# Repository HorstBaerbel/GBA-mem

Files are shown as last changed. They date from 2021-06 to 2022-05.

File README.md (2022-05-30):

<p align="center">
    <span>
        <font size="12">Here be dragons🐉!</font></br>
        <font size="4">This killed my GBA. I probably fried the power supply IC. I'm leaving this here for academic purposes...</font>
    </span>
</p>

# Game Boy Advance faster EWRAM hack

The GBA has 256kB of external work RAM in the form of an 128kx16 SRAM chip with 70ns (M68AS128DL70N6), 85ns ([μPD442012AGY-BB85X-MJH](http://www.dexsilicium.com/Nec_D442012AGY.pdf)), or even 120ns ([HY62LF16206A-LT12C](https://www.alldatasheet.com/datasheet-pdf/pdf/96180/HYNIX/HY62LF16206A.html)) access time, depending on the chip (good hardware database [here](https://gbhwdb.gekkio.fi/consoles/agb/)). The regular EWRAM access speed is 2 wait states (3/3/6 clock cycles) for 1/2/4 bytes of data. Setting the [undocumented EWRAM wait states flags](http://problemkaputt.de/gbatek.htm#gbasystemcontrol) to 0Eh allows you to speed up EWRAM access to 1 wait state (2/2/4 clock cycles). Setting it to 0Fh will crash / lock up the GBA though, because 0 wait states are out of the specs of all SRAM chips ever used in the GBA / GBA SP and GBA Micro (access times must be < 62ns) and EWRAM gets corrupted (see [testing memory](#testing-memory)). The choice of those SRAM chips back in 2000 was probably due availability and keeping the system costs down, but 20 years later there are cheap SRAM chips available with as low as 10ns access time, so...

## The hardware

This aims to replace the GBAs SRAM chip with a faster chip on a carrier board, because there seem to be no pin-compatible models anymore. The old models used a TSOP-I-48 footprint, newer models use a TSOP-II-44 footprint and all have a very different pinout.

<p align="center">
    <span>
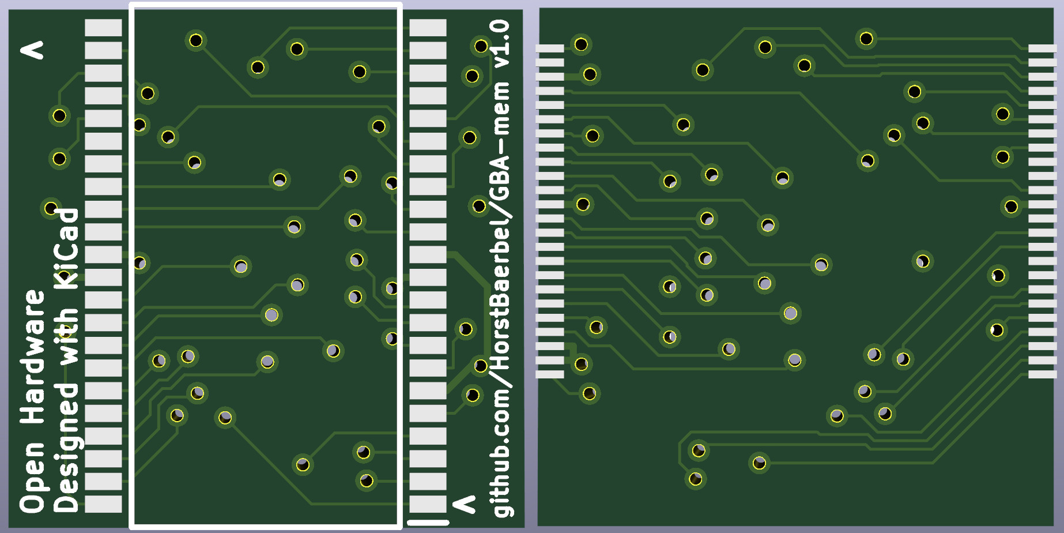
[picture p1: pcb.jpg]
schematics
        
    </span>
</p>

Supposedly compatible SRAM chips for the board:

| Model | min. access time | max. power draw | working |
| --- | --- | --- | --- |
| [IS62WV12816BLL-55TLI / -55BLI](http://www.issi.com/WW/pdf/62WV12816ALL.pdf) | 55ns | ~25mA | NO (tested) |
| [IS62WV12816EBLL-45TLI](http://www.issi.com/WW/pdf/62-65WV12816EALL-BLL.pdf) | 45ns | ~15mA | ? |
| [CY62136FV30LL-45ZSXIT / -45ZSXI / -45ZSXA](https://www.cypress.com/file/43866/download) | 45ns | ~18mA | ? |
| [CY62136ESL-45ZSXI](https://www.mouser.de/datasheet/2/100/001-48147_CY62136ESL_MoBL_R_2-Mbit_128_K_X_16_Stat-319203.pdf) | 45ns | ~20mA | ? |

The power draw of the replacement chips seems to be comparable to that of the originals. I'd go with the IS62WV12816EBLL-45TLI if you can find it, because of the lowest power draw.

## Making your own boards

The [KiCad](KiCad) directory contains the schematics and PCB layout and also gerber files (exported for JLPCB). I chose [JLPCB](https://jlcpcb.com) as a manufacturer in this case and a board thickness of 0.8mm. Remember to get a stencil made for both sides.

### Soldering

I opted for [ChipQuik Sn42/Bi58 TS391LT](https://www.amazon.de/gp/product/B0195V1QEI) solder paste because of its low melting point of 138°C. This makes it easier to solder and you need to heat up the GBA mainboard less. You can 3D-print a [PCB holder](STL/PCB_holder.stl) for the PCB to apply solder paste with the stencil:

<p align="center">
    <span>
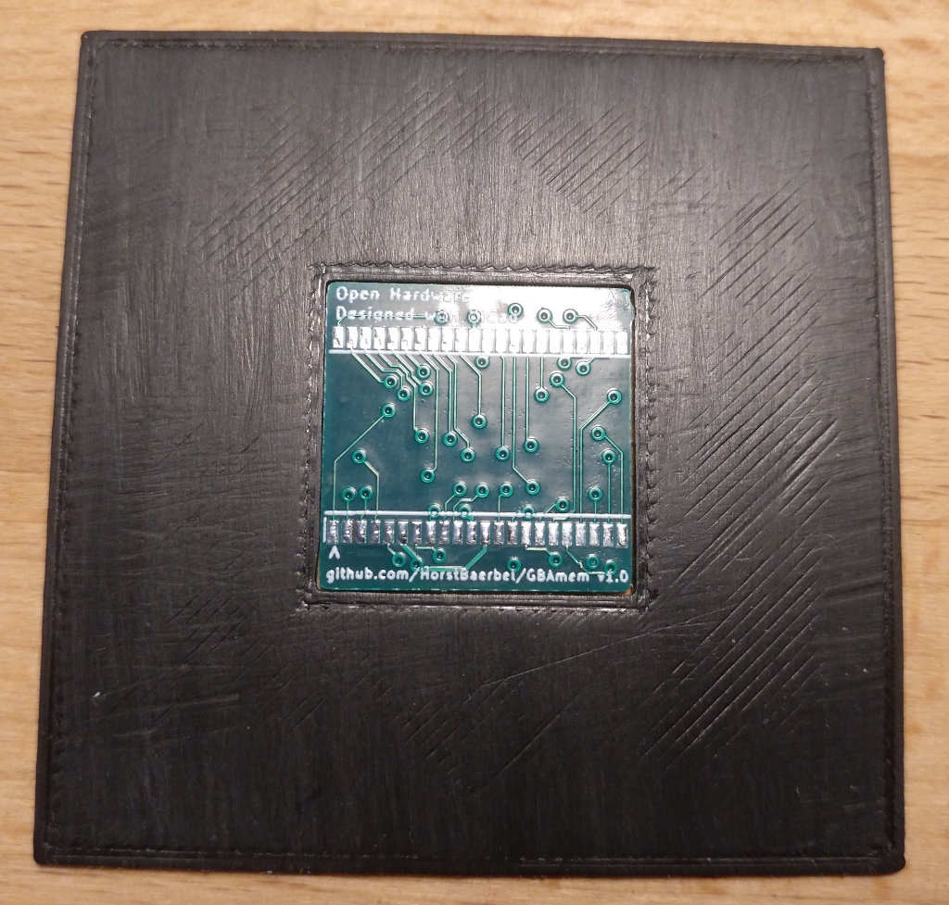
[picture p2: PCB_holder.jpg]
PCB holder
        
    </span>
</p>

It will test the ROM read, EWRAM read / write and IWRAM ⟷ EWRAM copy speed (startup default, Button **A**). Memory is copied in 24kB blocks, so this is not the max. speed possible, but gives a ballpark number. You can also test the memory for errors ([Memtest86+](http://www.memtest.org/)-like, Button **B**). Buttons **L** and **R** let you increase or decrease the EWRAM timings, **⟵** and **⟶** let you increase or decrease the ROM wait states and **START** reboots the GBA. The source code can be found in the [src](src) directory.  
**Theoretical** EWRAM SRAM chip transfer speeds should be: Clock speed * 2 (16 bit SRAM width) / (1 + wait states) ⟷ 16 * 1024 * 1024 * 2 / (1 + w) = 10.6 MB/s (default 2 wait states) and 32 MB/s (0 wait states).

## How to build the test binary?

### From the command line

* You **must** have [CMake](https://cmake.org/) 3.1.0 or higher, [devkitPro / devKitARM](https://devkitpro.org) r58 or higher [installed](https://devkitpro.org/wiki/Getting_Started).
* Navigate to the [src](src) folder, then:

```sh
mkdir build && cd build
cmake -DCMAKE_BUILD_TYPE=Release ..
make -j $(grep -c '^processor' /proc/cpuinfo 2>/dev/null)
```

### From Visual Studio Code

* You **must** have [CMake](https://cmake.org/), [devkitPro / devKitARM](https://devkitpro.org) r54 or higher [installed](https://devkitpro.org/wiki/Getting_Started).
* **Must**: Install the "C/C++ extension" by Microsoft.
* **Recommended**: If you want intellisense functionality install the "C++ intellisense" extension by austin.
* **Must**: Install the "CMake Tools" extension by Microsoft.
* Restart / Reload Visual Studio Code if you have installed extensions.
* Open the GBAmem folder using "Open folder...".
* Choose "Unspecified" as your active CMake kit if asked. It then should be autodetected correctly.
* You should be able to build now using F7 and build + run using F5.

## License

If you want to build your own soft- or hardware based on this, you can. See the [MIT LICENSE](LICENSE).  
The "Modern DOS" 8x8 font is from [Jayvee Enaguas](https://notabug.org/HarvettFox96/ttf-moderndos) and used by [CC0](https://notabug.org/HarvettFox96/ttf-moderndos/src/master/LICENSE).  
The CMake build scripts / toolchain is from [Thomas Farr](https://github.com/Xtansia/3ds-cmake) and uses the [MIT LICENSE](3ds-cmake/LICENSE).

## Todo

* Move all of the code to IWRAM
* Use framework
* Test IS62WV12816EBLL-45TLI
* Try out [AGZ PCB](https://github.com/Zekfoo/AGZ)

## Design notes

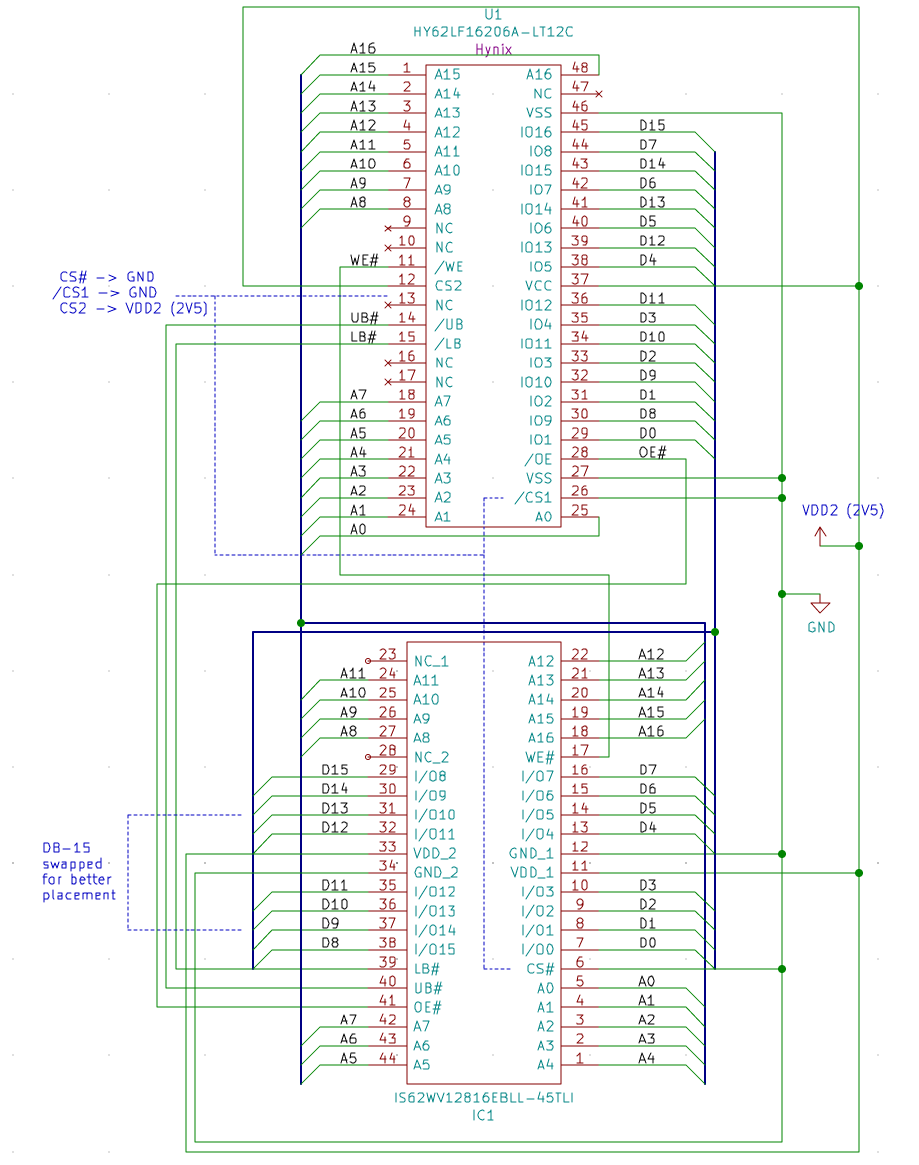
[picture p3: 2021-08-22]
schematics.png

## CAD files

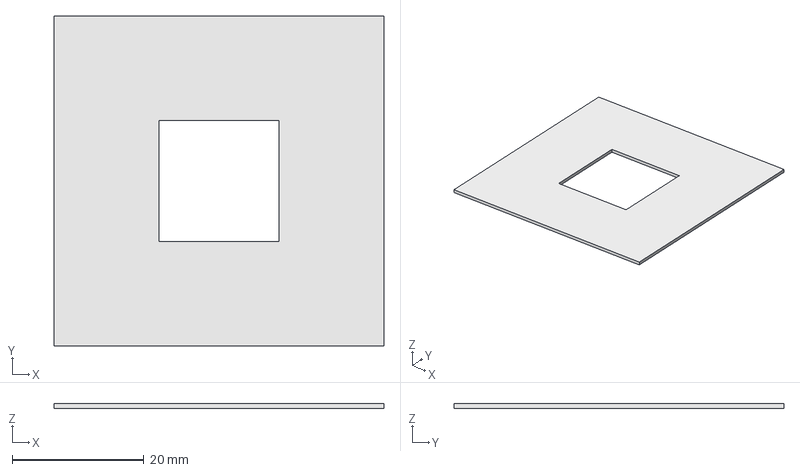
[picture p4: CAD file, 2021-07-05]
STL/PCB_holder.FCStd
50.0 x 50.0 x 0.7 mm

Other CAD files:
STL/PCB_holder.stl

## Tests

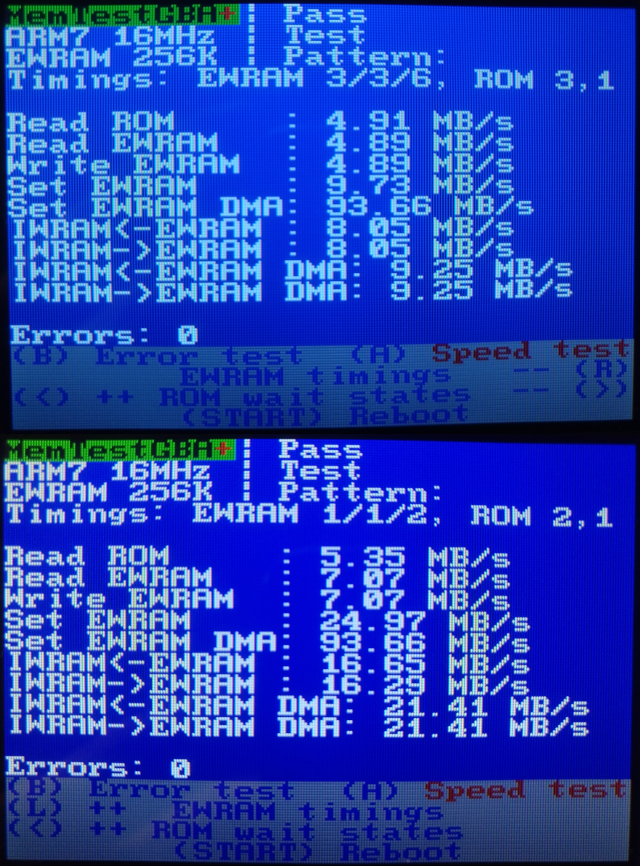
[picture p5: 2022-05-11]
MemTestGBA.png

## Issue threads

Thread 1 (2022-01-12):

About this project

StephS, 2022-01-12:
Hey, I found this thinking the same thing, and it looks like you're the only one who has tried this.
But I see your warning, and the short table that seems to state that none of the memory worked.
Any idea what went wrong?

HorstBaerbel, 2022-01-12:
The GBA started the test ROM for a couple of seconds, but then died. I think the power supply was not sufficient for the chip I used (IS62WV12816BLL). I unsoldered the chip and the GBA starts and boots due to IWRAM being available, but when loading ROMs it crashes obviously. I haven't found the time to try soldering the old RAM chip again or trying out the IS62WV12816EBLLs I have lying around here.
There's a [GBA PCB / circuit redesign](https://github.com/Zekfoo/AGZ) that would be perfect for trying this out.

HorstBaerbel, 2022-01-12:
You can also find me on [discord/gbadev](https://discord.io/gbadev) if you want.

Closed 2022-01-12.

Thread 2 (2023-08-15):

Exploring the Feasibility of Expanding GBA Memory

panzoe, 2023-08-15:
Hello,

I came across this project and I'm genuinely impressed by its capabilities. However, it seems the project primarily focuses on achieving higher memory frequencies. I'd like to inquire whether it's possible to expand the memory capacity of the GBA. The current memory size is quite restrictive, especially when it comes to creating custom programs for the GBA.

Is it feasible to consider replacing the existing eWRAM chip or even introducing an additional eWRAM-like chip into the circuit to provide more memory for program utilization? For instance, is there a way to increase the memory to 64/128/256/512MB?

HorstBaerbel, 2023-08-15:
Hi panzoe.
The GBA CPU only has enough address lines for addressing 256kB of external memory / EWRAM. Switching memory chips / address lanes is not a good idea due random memory accesses being impossible and afaik the stack being in EWRAM too. So, no I guess.
That said 256kB EWRAM + 32kB IWRAM + 96kB VRAM is a good amount of memory for such a system. If that's not enough for you, you're probably "doing it wrong". On limited systems you have to get creative, cut corners, pre-process as much as you can.

Closed 2023-08-15.

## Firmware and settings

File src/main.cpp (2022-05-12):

#include <gba_base.h>
#include <gba_input.h>
#include <gba_interrupt.h>
#include <gba_systemcalls.h>
#include <gba_timers.h>
#include <gba_video.h>

#include "data/romdata.h"
#include "dma.h"
#include "itoa.h"
#include "memory.h"
#include "tui.h"

struct alignas(4) TestConfig
{
	uint8_t *dest = nullptr;
	uint32_t destSize = 0;
	const uint8_t *src = nullptr;
	uint32_t srcSize = 0;
};

struct alignas(4) SpeedResult
{
	int32_t romTime = 0;
	uint32_t bytesPerRomTest = 0;
	int32_t readTime = 0;
	int32_t writeTime = 0;
	int32_t setTime = 0;
	int32_t setDMATime = 0;
	int32_t copyToTime = 0;
	int32_t copyFromTime = 0;
	int32_t copyToDMATime = 0;
	int32_t copyFromDMATime = 0;
	uint32_t bytesPerRamTest = 0;
};

// define all functions here, so we can put them into IWRAM
#define NOINLINE __attribute__((noinline))

void printSpeed(int32_t time, uint32_t bytes, uint16_t x, uint16_t y, TUI::Color backColor, TUI::Color textColor) IWRAM_CODE;
template <typename F>
void runBlockwise(F func, const TestConfig &config) IWRAM_CODE;
void readBlock(const void *source, uint32_t value, uint32_t nrOfWords) IWRAM_CODE;
void writeBlock(void *destination, uint32_t value, uint32_t nrOfWords) IWRAM_CODE;
template <typename F>
int32_t runFunctionBlockwise(F func, const TestConfig &config, uint32_t nrOfCycles) IWRAM_CODE;
template <typename F>
int32_t runFunctionOnSrc(F func, const TestConfig &config, uint32_t nrOfCycles) IWRAM_CODE;
template <typename F>
int32_t runFunctionOnDest(F func, const TestConfig &config, uint32_t nrOfCycles) IWRAM_CODE;
SpeedResult runSpeedTest(const TestConfig &config, uint32_t nrOfCycles) IWRAM_CODE;
uint32_t testPattern(uint32_t index) IWRAM_CODE;
uint32_t runRamErrorTest(const TestConfig &config, uint32_t nrOfCycles, uint32_t pattern) IWRAM_CODE;
uint32_t runRomErrorTest(const TestConfig &config, uint32_t nrOfCycles) IWRAM_CODE;
int32_t getTime() NOINLINE IWRAM_CODE;
void updateTime() NOINLINE IWRAM_CODE;
void updateBlinkState() IWRAM_CODE;
void updateInput() IWRAM_CODE;
void printTestState() IWRAM_CODE;
void printRamTimings() IWRAM_CODE;
void printRomWaitStates() IWRAM_CODE;
int main() IWRAM_CODE;

// ------------------------------------------------------------------------------------------------

static volatile uint32_t rwdummy;

template <typename F>
void runBlockwise(F func, const TestConfig &config)
{
	if (config.srcSize < config.destSize)
	{
		const uint32_t nrOfBlocks = config.destSize / config.srcSize;
		auto d = config.dest;
		for (uint32_t i = 0; i < nrOfBlocks; i++)
		{
			func(d, reinterpret_cast<const uint32_t *>(config.src), config.srcSize >> 2);
			d += config.srcSize;
		}
	}
	else if (config.srcSize > config.destSize)
	{
		const uint32_t nrOfBlocks = config.srcSize / config.destSize;
		auto s = config.src;
		for (uint32_t i = 0; i < nrOfBlocks; i++)
		{
			func(config.dest, reinterpret_cast<const uint32_t *>(s), config.destSize >> 2);
			s += config.destSize;
		}
	}
	else
	{
		func(config.dest, reinterpret_cast<const uint32_t *>(config.src), config.srcSize >> 2);
	}
}

void readBlock(const void *source, uint32_t value, uint32_t nrOfWords)
{
	uint32_t v = value;
	auto src32 = reinterpret_cast<const uint32_t *>(source);
	for (uint32_t i = 0; i < nrOfWords; i++)
	{
		v += src32[i];
	}
	rwdummy = v;
}

void writeBlock(void *destination, uint32_t value, uint32_t nrOfWords)
{
	uint32_t v = value;
	auto dest32 = reinterpret_cast<uint32_t *>(destination);
	for (uint32_t i = 0; i < nrOfWords; i++)
	{
		dest32[i] = v++;
	}
	rwdummy = v;
}

// ------------------------------------------------------------------------------------------------

template <typename F>
int32_t runFunctionBlockwise(F func, const TestConfig &config, uint32_t nrOfCycles)
{
	auto startTime = getTime();
	for (uint32_t cycle = 0; cycle < nrOfCycles; cycle++)
	{
		runBlockwise(func, config);
	}
	return getTime() - startTime;
}

template <typename F>
int32_t runFunctionOnSrc(F func, const TestConfig &config, uint32_t nrOfCycles)
{
	auto startTime = getTime();
	for (uint32_t cycle = 0; cycle < nrOfCycles; cycle++)
	{
		func(config.src, 0x12345678, config.srcSize >> 2);
	}
	return getTime() - startTime;
}

template <typename F>
int32_t runFunctionOnDest(F func, const TestConfig &config, uint32_t nrOfCycles)
{
	auto startTime = getTime();
	for (uint32_t cycle = 0; cycle < nrOfCycles; cycle++)
	{
		func(config.dest, 0x12345678, config.destSize >> 2);
	}
	return getTime() - startTime;
}

SpeedResult runSpeedTest(const TestConfig &config, uint32_t nrOfCycles)
{
	SpeedResult result = {0, ROM_DATA_SIZE * 4 * nrOfCycles, 0, 0, 0, 0, 0, 0, 0, 0, config.destSize * nrOfCycles};
	auto rom = config;
	rom.src = reinterpret_cast<const uint8_t *>(ROM_DATA);
	rom.srcSize = ROM_DATA_SIZE * 4;
	result.romTime = runFunctionOnSrc(readBlock, rom, nrOfCycles);
	auto to = config;
	result.readTime = runFunctionOnDest(readBlock, to, nrOfCycles);
	result.writeTime = runFunctionOnDest(writeBlock, to, nrOfCycles);
	result.setTime = runFunctionOnDest(Memory::memset32, to, nrOfCycles);
	result.setDMATime = runFunctionOnDest(DMA::dma_fill32, to, nrOfCycles);
	TestConfig from = {const_cast<uint8_t *>(config.src), config.srcSize, config.dest, config.destSize};
	result.copyFromTime = runFunctionBlockwise(Memory::memcpy32, from, nrOfCycles);
	result.copyToTime = runFunctionBlockwise(Memory::memcpy32, to, nrOfCycles);
	result.copyFromDMATime = runFunctionBlockwise(DMA::dma_copy32, from, nrOfCycles);
	result.copyToDMATime = runFunctionBlockwise(DMA::dma_copy32, to, nrOfCycles);
	return result;
}

// ------------------------------------------------------------------------------------------------

#define TEST_PATTERN_COUNT 128

uint32_t testPattern(uint32_t index)
{
	if (index < 32)
	{
		return (uint32_t(0b1) << index);
	}
	else if (index < 64)
	{
		return (uint32_t(0b11) << (index - 32));
	}
	else if (index < 96)
	{
		return (uint32_t(0b101) << (index - 64));
	}
	else if (index < 128)
	{
		return (uint32_t(0b111) << (index - 96));
	}
	return 0;
}

uint32_t runRamErrorTest(const TestConfig &config, uint32_t nrOfCycles, uint32_t pattern)
{
	uint32_t nrOfErrors = 0;
	auto complement = ~pattern;
	auto count = config.destSize >> 2;
	auto src32 = reinterpret_cast<uint32_t *>(config.dest);
	for (uint32_t cycle = 0; cycle < nrOfCycles; cycle++)
	{
		// Moving inversions algorithm (sort of)
		DMA::dma_fill32(config.dest, pattern, count);
		for (int32_t i = 0; i < static_cast<int32_t>(count); i++)
		{
			nrOfErrors += src32[i] != pattern ? 1 : 0;
			src32[i] = complement;
		}
		for (int32_t i = count - 1; i >= 0; i--)
		{
			nrOfErrors += src32[i] != complement ? 1 : 0;
			src32[i] = pattern;
		}
		auto nrOfDash = (cycle * 13) / nrOfCycles;
		TUI::printChars('#', nrOfDash, 18, 1, TUI::Color::Blue, TUI::Color::White);
		TUI::printChars(' ', 13 - nrOfDash, 18 + nrOfDash, 1, TUI::Color::Blue, TUI::Color::White);
	}
	return nrOfErrors;
}

uint32_t runRomErrorTest(const TestConfig &config, uint32_t nrOfCycles)
{
	uint32_t nrOfErrors = 0;
	const auto count = ROM_DATA_SIZE;
	auto src32 = ROM_DATA;
	for (uint32_t cycle = 0; cycle < nrOfCycles; cycle++)
	{
		for (uint32_t i = 0; i < count; i++)
		{
			nrOfErrors += src32[i] != i;
		}
	}
	return nrOfErrors;
}

// ------------------------------------------------------------------------------------------------

void printSpeed(int32_t time, uint32_t bytes, uint16_t x, uint16_t y, TUI::Color backColor, TUI::Color textColor)
{
	int32_t MBperS = ((int64_t)bytes << 4) / ((int64_t)time);
	TUI::printString(" MB/s ", x + TUI::printFloat(MBperS, x, y, backColor, textColor), y, backColor, textColor);
}

// ------------------------------------------------------------------------------------------------

static bool blinkState{false};
static bool testSpeed{true};
static uint32_t ramWaitStateIndex{0};
static const uint32_t RamWaitStates[]{Memory::WaitEwramNormal, Memory::WaitEwramFast, Memory::WaitEwramLudicrous};
static const char *RamWaitStateStrings[]{"3/3/6", "2/2/4", "1/1/2"};
static const char *RamWaitStateOptionStrings[]{"        EWRAM timings   -- (R)", "(L) ++  EWRAM timings   -- (R)", "(L) ++  EWRAM timings         "};
static uint32_t romWaitStateIndex{1};
static const uint32_t RomWaitStates[]{Memory::WaitCntSlowest, Memory::WaitCntSlow, Memory::WaitCntNormal, Memory::WaitCntFast};
static const char *RomWaitStateStrings[]{"8,2", "4,2", "3,1", "2,1"};
static const char *RomWaitStateOptionStrings[]{"       ROM wait states  -- (>)", "(<) ++ ROM wait states  -- (>)", "(<) ++ ROM wait states  -- (>)", "(<) ++ ROM wait states        "};
constexpr uint32_t CyclesSpeed{8};
constexpr uint32_t CyclesErrors{4};
static const TestConfig testConfig{Memory::EWRAM_BLOCK, Memory::EWRAM_ALLOC_SIZE, Memory::IWRAM_BLOCK, Memory::IWRAM_ALLOC_SIZE};

constexpr int32_t TimerIncrement{164}; // 65536/164=400 -> 1/400=2.5ms
static int32_t TimerTicks{0};		   // current wall clock in s in 16.16 format

int32_t getTime()
{
	return TimerTicks;
}

void updateTime()
{
	TimerTicks += TimerIncrement;
}

void updateBlinkState()
{
	// blink UI elements
	blinkState = !blinkState;
	TUI::printChar('+', 10, 0, TUI::Color::Green, blinkState ? TUI::Color::Red : TUI::Color::Black);
	printTestState();
}

void printTestState()
{
	TUI::printString("Error test", 4, 16, TUI::Color::LightGray, !testSpeed && blinkState ? TUI::Color::Red : TUI::Color::Blue);
	TUI::printString("Speed test", 20, 16, TUI::Color::LightGray, testSpeed && blinkState ? TUI::Color::Red : TUI::Color::Blue);
}

void printRamTimings()
{
	TUI::printString(RamWaitStateStrings[ramWaitStateIndex], 15, 3, TUI::Color::Blue, TUI::Color::White);
	TUI::printString(RamWaitStateOptionStrings[ramWaitStateIndex], 0, 17, TUI::Color::LightGray, TUI::Color::Blue);
}

void printRomWaitStates()
{
	TUI::printString(RomWaitStateStrings[romWaitStateIndex], 26, 3, TUI::Color::Blue, TUI::Color::White);
	TUI::printString(RomWaitStateOptionStrings[romWaitStateIndex], 0, 18, TUI::Color::LightGray, TUI::Color::Blue);
}

void updateInput()
{
	scanKeys();
	auto keys = keysDown();
	// check if need to change EWRAM timings
	auto ramWaitStateIndexBefore = ramWaitStateIndex;
	if (keys & KEY_L)
	{
		ramWaitStateIndex = ramWaitStateIndex > 0 ? ramWaitStateIndex - 1 : 0;
	}
	else if (keys & KEY_R)
	{
		ramWaitStateIndex = ramWaitStateIndex < 2 ? ramWaitStateIndex + 1 : 2;
	}
	if (ramWaitStateIndex != ramWaitStateIndexBefore)
	{
		Memory::RegWaitEwram = RamWaitStates[ramWaitStateIndex];
		printRamTimings();
	}
	// check if need to change ROM wait states
	auto romWaitStateIndexBefore = romWaitStateIndex;
	if (keys & KEY_LEFT)
	{
		romWaitStateIndex = romWaitStateIndex > 0 ? romWaitStateIndex - 1 : 0;
	}
	else if (keys & KEY_RIGHT)
	{
		romWaitStateIndex = romWaitStateIndex < 3 ? romWaitStateIndex + 1 : 3;
	}
	if (romWaitStateIndex != romWaitStateIndexBefore)
	{
		Memory::RegWaitCnt = RomWaitStates[romWaitStateIndex];
		printRomWaitStates();
	}
	// check if we need to change the test mode
	auto testSpeedBefore = testSpeed;
	if (keys & KEY_A)
	{
		testSpeed = true;
	}
	else if (keys & KEY_B)
	{
		testSpeed = false;
	}
	if (testSpeed != testSpeedBefore)
	{
		printTestState();
	}
	// check if we need to reboot
	if (keys & KEY_START)
	{
		SystemCall(0x26);
	}
}

int main()
{
	// set startup waitstates for GamePak ROM and EWRAM
	Memory::RegWaitCnt = Memory::WaitCntSlow;
	Memory::RegWaitEwram = Memory::WaitEwramNormal;
	// set up UI
	TUI::setup();
	// build start screen
	TUI::fillBackground(TUI::Color::Blue);
	TUI::fillBackgroundRect(0, 18, TUI::Width, 2, TUI::Color::LightGray);
	TUI::printString("MemTestGBA+", 0, 0, TUI::Color::Green, TUI::Color::Black);
	TUI::printString("| Pass", 11, 0, TUI::Color::Blue, TUI::Color::White);
	TUI::printString("ARM7 16MHz | Test", 0, 1, TUI::Color::Blue, TUI::Color::White);
	TUI::printString("EWRAM 256K | Pattern:", 0, 2, TUI::Color::Blue, TUI::Color::White);
	TUI::printString("Timings: EWRAM 3/3/6, ROM 4,2", 0, 3, TUI::Color::Blue, TUI::Color::White);
	TUI::printString("Read ROM      :", 0, 5, TUI::Color::Blue, TUI::Color::White);
	TUI::printString("Read EWRAM    :", 0, 6, TUI::Color::Blue, TUI::Color::White);
	TUI::printString("Write EWRAM   :", 0, 7, TUI::Color::Blue, TUI::Color::White);
	TUI::printString("Fill EWRAM    :", 0, 8, TUI::Color::Blue, TUI::Color::White);
	TUI::printString("Fill EWRAM DMA:", 0, 9, TUI::Color::Blue, TUI::Color::White);
	TUI::printString("IWRAM<-EWRAM  :", 0, 10, TUI::Color::Blue, TUI::Color::White);
	TUI::printString("IWRAM->EWRAM  :", 0, 11, TUI::Color::Blue, TUI::Color::White);
	TUI::printString("IWRAM<-EWRAM DMA:", 0, 12, TUI::Color::Blue, TUI::Color::White);
	TUI::printString("IWRAM->EWRAM DMA:", 0, 13, TUI::Color::Blue, TUI::Color::White);
	TUI::printString("Errors: 0, 0", 0, 15, TUI::Color::Blue, TUI::Color::White);
	TUI::printString("(B) Error test  (A) Speed test", 0, 16, TUI::Color::LightGray, TUI::Color::Blue);
	TUI::printString(RamWaitStateOptionStrings[ramWaitStateIndex], 0, 17, TUI::Color::LightGray, TUI::Color::Blue);
	TUI::printString(RomWaitStateOptionStrings[romWaitStateIndex], 0, 18, TUI::Color::LightGray, TUI::Color::Blue);
	TUI::printString("        (START) Reboot        ", 0, 19, TUI::Color::LightGray, TUI::Color::Blue);
	printRamTimings();
	printRomWaitStates();
	// start wall clock
	irqInit();
	// set up time to increase time every ~2.5ms
	irqSet(irqMASKS::IRQ_TIMER3, updateTime);
	irqEnable(irqMASKS::IRQ_TIMER3);
	REG_TM3CNT_L = 65536 - TimerIncrement;
	REG_TM3CNT_H = TIMER_START | TIMER_IRQ | 2;
	// set up timer to call function every 1s
	irqSet(irqMASKS::IRQ_TIMER2, updateBlinkState);
	irqEnable(irqMASKS::IRQ_TIMER2);
	REG_TM2CNT_L = 65536 - 16384;
	REG_TM2CNT_H = TIMER_START | TIMER_IRQ | 3;
	// set up timer to call function every 150ms
	irqSet(irqMASKS::IRQ_TIMER1, updateInput);
	irqEnable(irqMASKS::IRQ_TIMER1);
	REG_TM1CNT_L = 65536 - 2458;
	REG_TM1CNT_H = TIMER_START | TIMER_IRQ | 3;
	// set up some variables
	uint32_t ramErrorCount = 0;
	uint32_t romErrorCount = 0;
	uint32_t patternIndex = 0;
	// start main loop
	do
	{
		if (testSpeed)
		{
			auto result = runSpeedTest(testConfig, CyclesSpeed);
			printSpeed(result.romTime, result.bytesPerRomTest, 16, 5, TUI::Color::Blue, TUI::Color::White);
			printSpeed(result.readTime, result.bytesPerRamTest, 16, 6, TUI::Color::Blue, TUI::Color::White);
			printSpeed(result.writeTime, result.bytesPerRamTest, 16, 7, TUI::Color::Blue, TUI::Color::White);
			printSpeed(result.setTime, result.bytesPerRamTest, 16, 8, TUI::Color::Blue, TUI::Color::White);
			printSpeed(result.setDMATime, result.bytesPerRamTest, 16, 9, TUI::Color::Blue, TUI::Color::White);
			printSpeed(result.copyFromTime, result.bytesPerRamTest, 16, 10, TUI::Color::Blue, TUI::Color::White);
			printSpeed(result.copyToTime, result.bytesPerRamTest, 16, 11, TUI::Color::Blue, TUI::Color::White);
			printSpeed(result.copyFromDMATime, result.bytesPerRamTest, 18, 12, TUI::Color::Blue, TUI::Color::White);
			printSpeed(result.copyToDMATime, result.bytesPerRamTest, 18, 13, TUI::Color::Blue, TUI::Color::White);
		}
		else
		{
			// test EWRAM reading / writing for errors
			auto pattern = testPattern(patternIndex);
			TUI::printInt(pattern, 16, 22, 2, TUI::Color::Blue, TUI::Color::White);
			ramErrorCount += runRamErrorTest(testConfig, CyclesErrors, pattern);
			auto ramErrorLength = TUI::printInt(ramErrorCount, 10, 8, 15, TUI::Color::Blue, ramErrorCount > 0 ? TUI::Color::Red : TUI::Color::White);
			patternIndex = patternIndex >= TEST_PATTERN_COUNT ? 0 : patternIndex + 1;
			auto nrOfDash = (patternIndex * 12) / TEST_PATTERN_COUNT;
			TUI::printChars('#', nrOfDash, 18, 0, TUI::Color::Blue, TUI::Color::White);
			TUI::printChars(' ', 12 - nrOfDash, 18 + nrOfDash, 0, TUI::Color::Blue, TUI::Color::White);
			// test ROM reading for errors
			romErrorCount += runRomErrorTest(testConfig, CyclesErrors);
			TUI::printString(", ", 8 + ramErrorLength, 15, TUI::Color::Blue, TUI::Color::White);
			TUI::printInt(romErrorCount, 10, 8 + ramErrorLength + 2, 15, TUI::Color::Blue, romErrorCount > 0 ? TUI::Color::Red : TUI::Color::White);
		}
	} while (true);
	return 0;
}

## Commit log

2021-06-23 Add build files and initial code
    [GBAmem.kicad_pcb]
2021-06-23 Update schematics and README
    [GBAmem.sch]
2021-06-24 Use demo framework as submodule
2021-06-24 Update demo framework
2021-06-25 Print strings using tiled backgrounds
2021-06-28 Print EWRAM speed
2021-06-28 Add keys to switch timing and restart
2021-06-30 Add more tests. Update framework
2021-06-30 Add DMA speeds
2021-06-30 Update framework. Use framework compiler flags
2021-06-30 Update framework
2021-07-05 Remove framework submodule
    [PCB_holder.FCStd, PCB_holder.stl]
2021-07-07 Fix DMA. Increase timer resolution
    [main.cpp]
2021-08-20 Always wait for DMA to finish
2021-08-20 Update PCB with positioning markers
    [GBAmem.kicad_pcb, GBAmem.sch]
2021-08-22 Update schematics
    [GBAmem.sch]
2022-05-12 Add ROM error testing. Start with slow ROM wait states
    [main.cpp]
